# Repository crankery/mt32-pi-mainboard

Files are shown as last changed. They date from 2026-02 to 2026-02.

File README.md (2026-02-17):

# mt32-pi-mainboard

A host board for the [mt32-pi project](https://github.com/dwhinham/mt32-pi). I've tried to use nothing but cheap through-hole parts off Aliexpress for this to make it easy to build. I had one of the LCD2004 modules in a drawer which is why I used that huge thing. The board is 100x100mm which should be pretty cheap to get fabricated.

> [!NOTE]
> This is untested and probably doesn't work. If it ends up working, I'll make a 3D printable case for it.

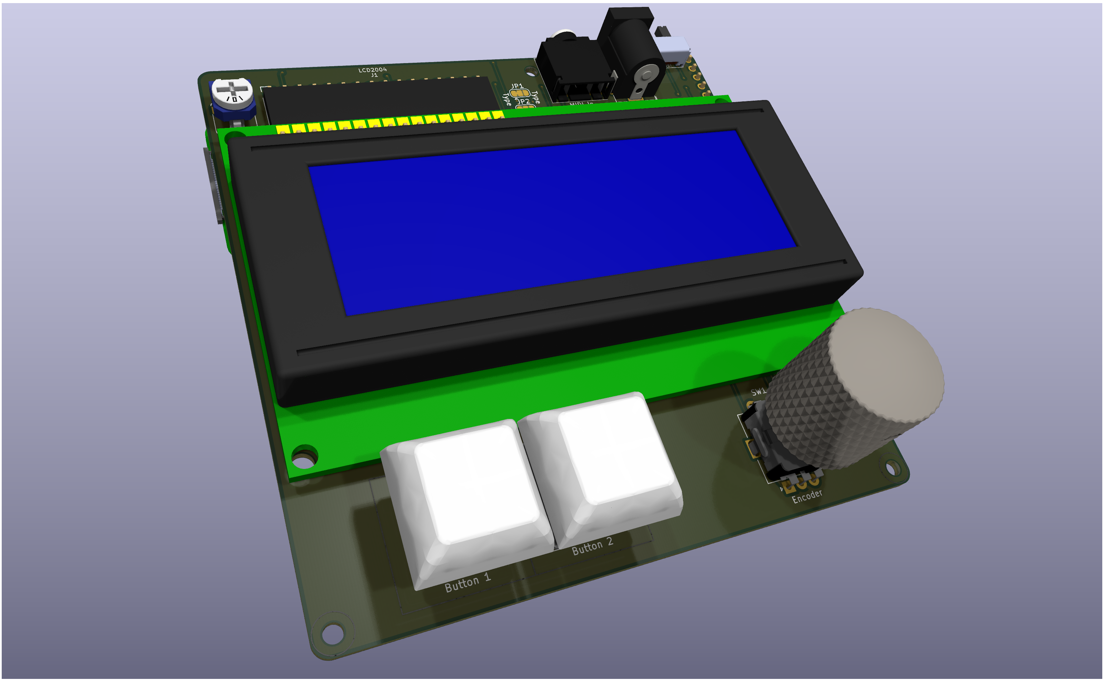
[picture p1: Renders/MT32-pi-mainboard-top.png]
Top


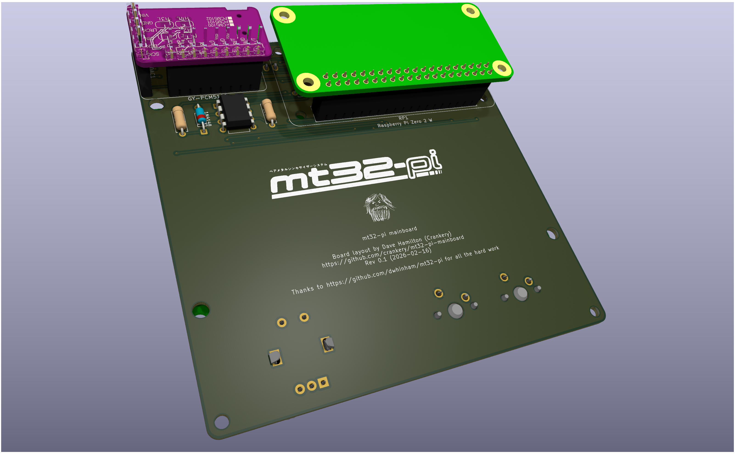
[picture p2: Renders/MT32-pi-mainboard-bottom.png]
Bottom


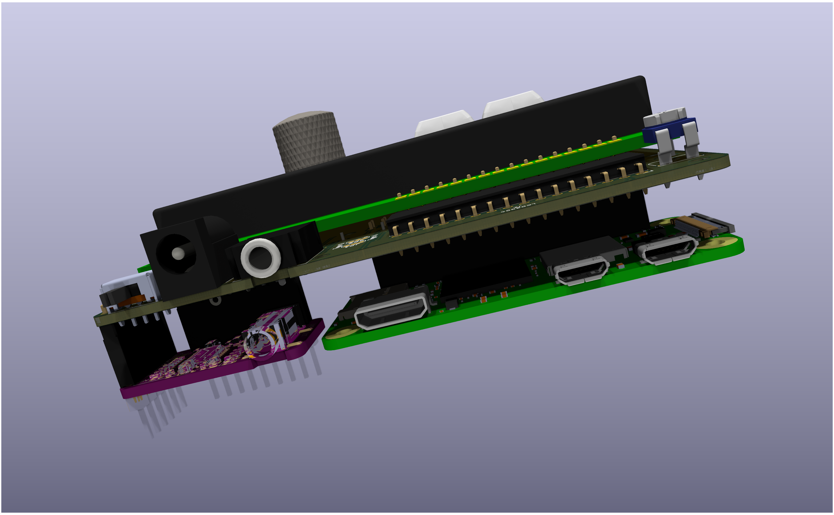
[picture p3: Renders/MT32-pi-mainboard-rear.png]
Rear


Yeah, the DAC module model I found has some weird transparancy issues in Kicad.

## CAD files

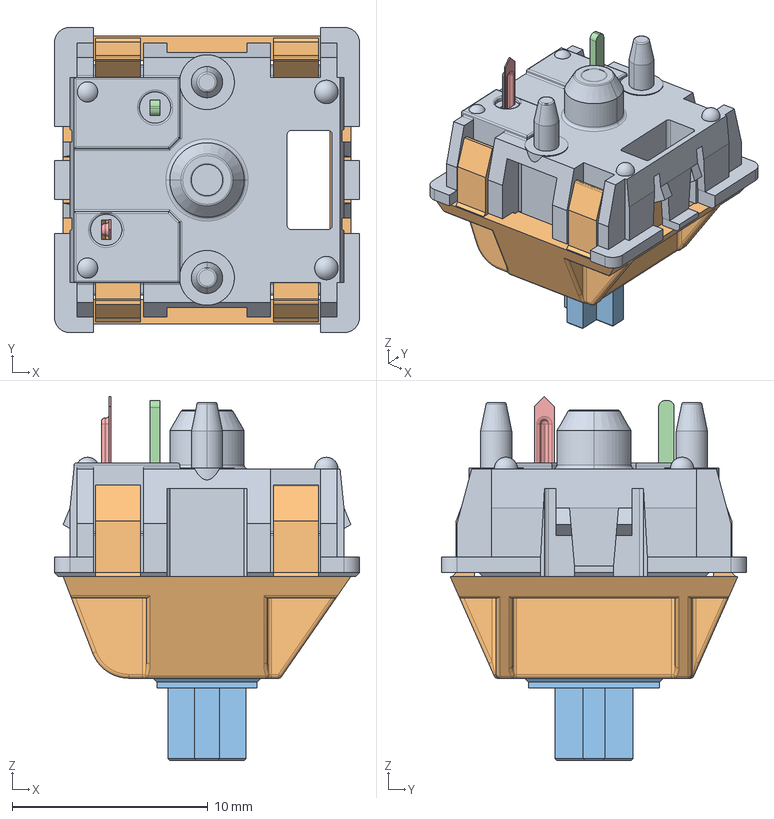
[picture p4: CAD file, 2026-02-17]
3D/asm_mx_asm_PCB.stp
15.6 x 15.6 x 18.6 mm
MX_DOWN
MX_UP
UP_MX
MX_PIN
MX_SPRING
MX_CLICK

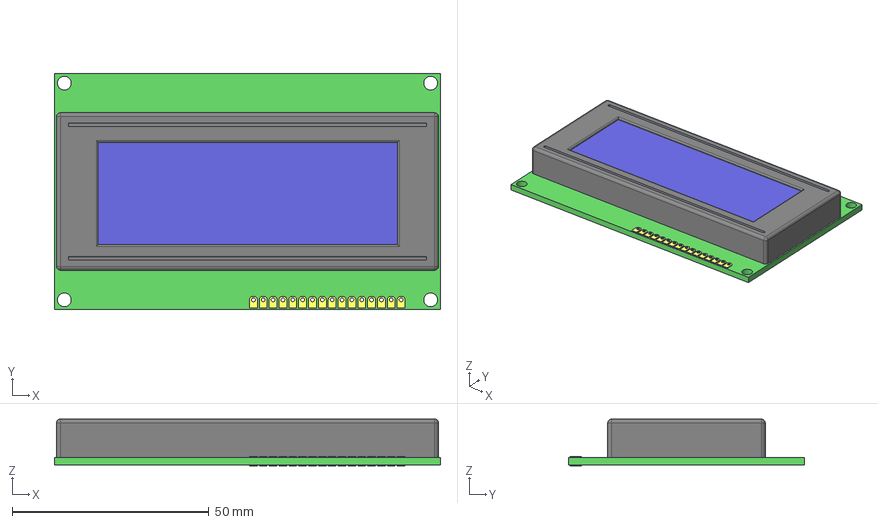
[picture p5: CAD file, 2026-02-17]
3D/LCD2004-simple.step
98.0 x 60.0 x 11.9 mm
LCD2007
PCB002
Islas001
Chasis002

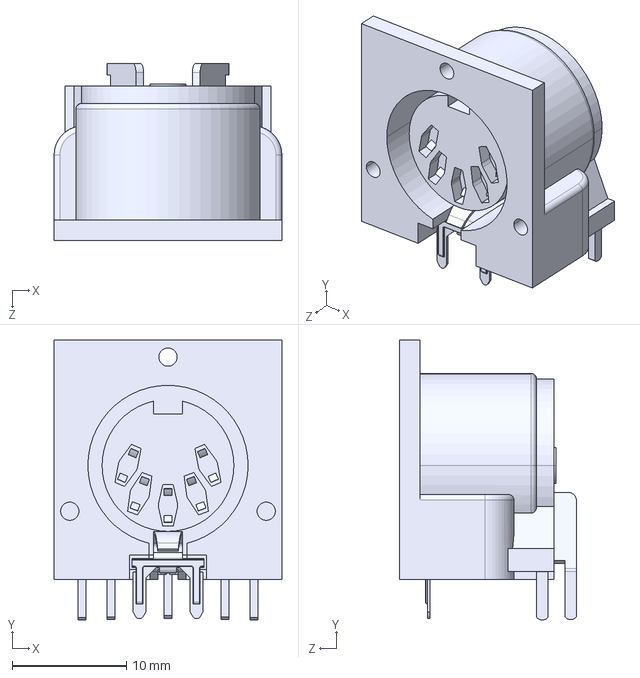
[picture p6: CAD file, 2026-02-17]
3D/57PC5F.step
20.0 x 24.5 x 15.5 mm

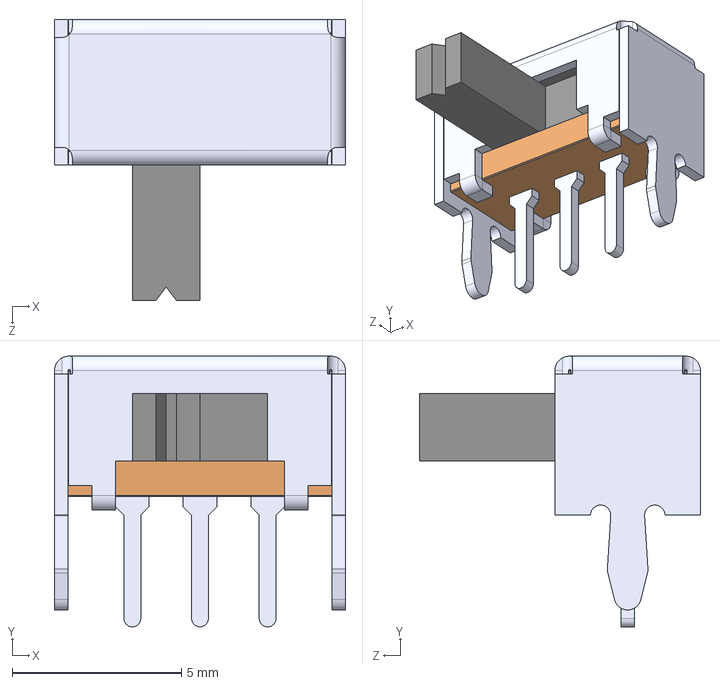
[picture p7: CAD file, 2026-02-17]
3D/SK12D07VG4.STEP
8.60 x 8.00 x 8.30 mm

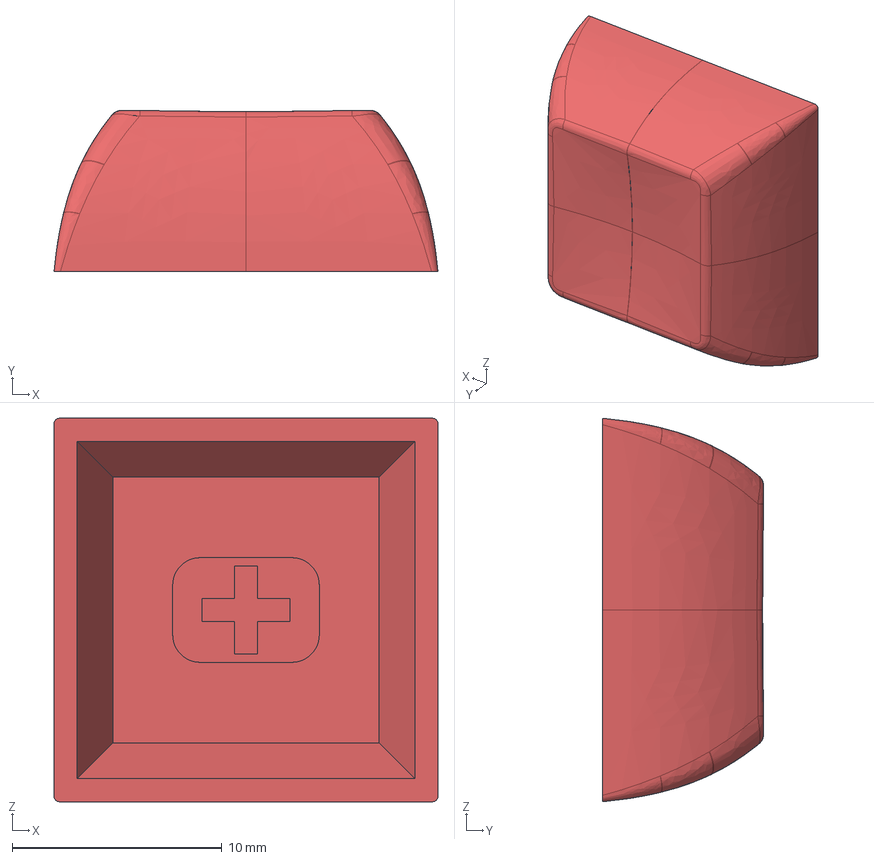
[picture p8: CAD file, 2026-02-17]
3D/DSA_Keycap_Red_CherryMX.step
18.3 x 7.69 x 18.3 mm

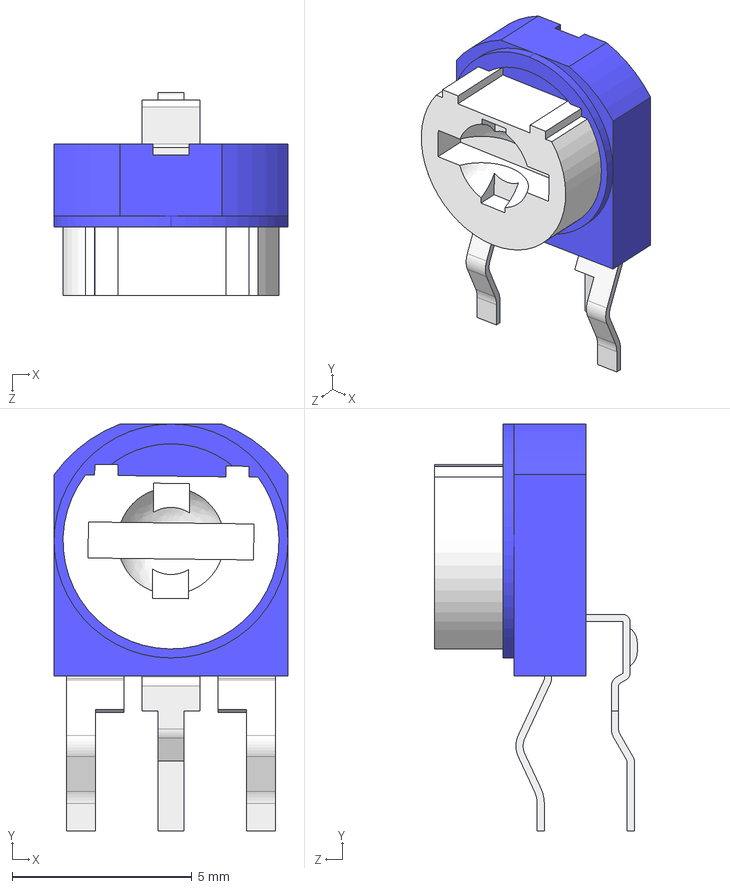
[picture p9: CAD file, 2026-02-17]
3D/RM-063.STEP
6.50 x 11.3 x 5.63 mm
User Library-RM-063_d1
User Library-RM-063_d2
User Library-RM-063_d3l
User Library-RM-063_d3r
User Library-RM-063_d3c

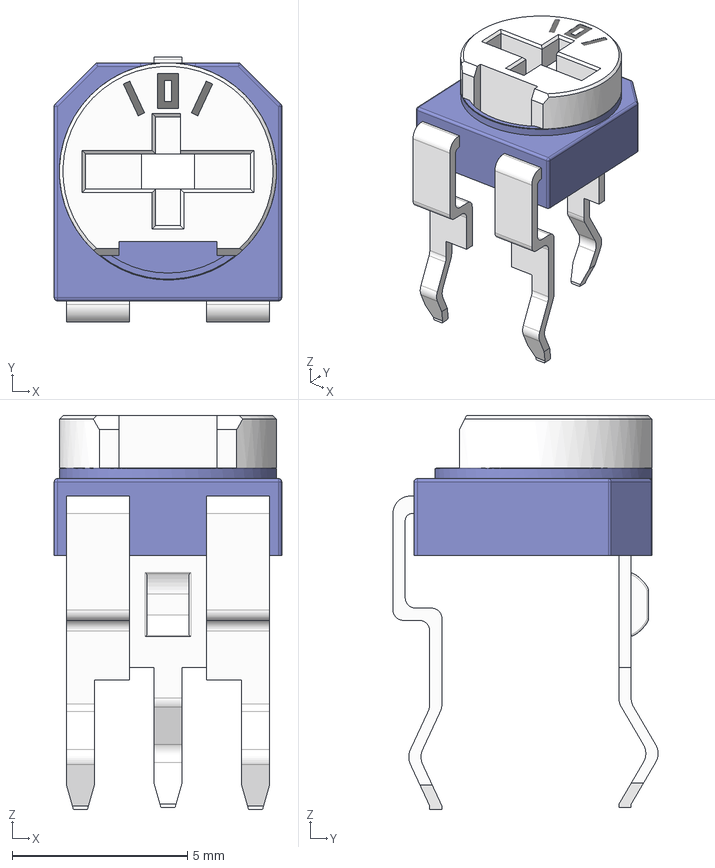
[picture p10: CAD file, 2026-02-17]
3D/RM-065.step
6.50 x 7.57 x 11.2 mm

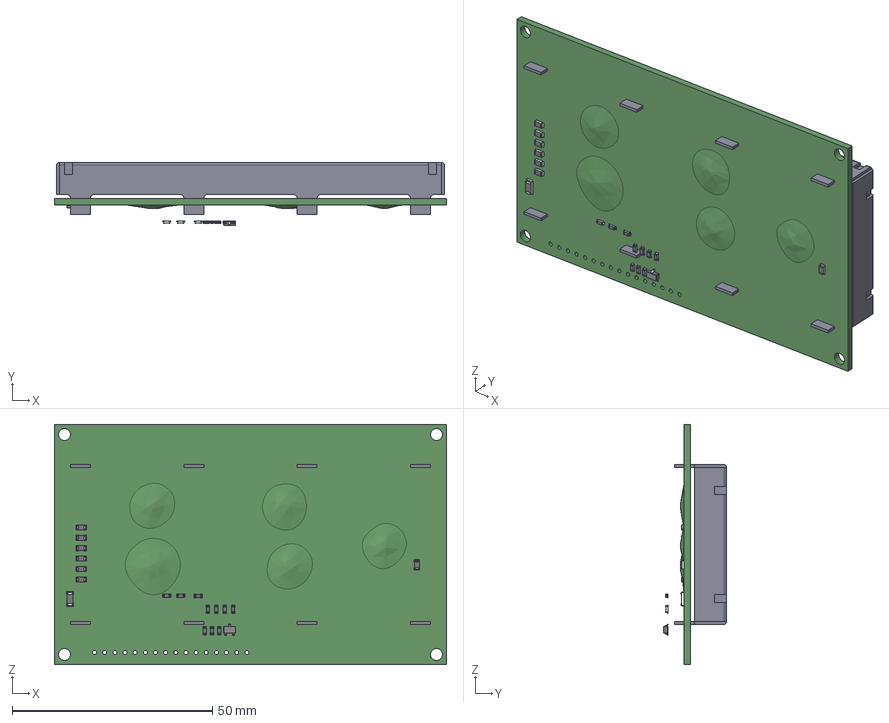
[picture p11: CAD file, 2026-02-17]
3D/lcd2004.step
98.0 x 15.8 x 60.0 mm
LCD2004 IIC_I2C, 20x4
LCD2004 IIC_I2C, 20x005
SMD rezistory_0603
SMD rezistory_0604
SMD rezistory_0605
SMD rezistory_0607
SMD rezistory_0608
SMD rezistory_0609
SMD rezistory_0611
SMD rezistory_0612
SMD rezistory_0613
SMD rezistory_0615
SMD rezistory_0616
SMD rezistory_0617
SMD rezistory_1206
SMD rezistory_1207
SMD rezistory_1208
SMD rezistory_0805
SMD rezistory_1210
SMD rezistory_1211
SMD rezistory_1213
SMD rezistory_1214
SMD rezistory_1215
SMD rezistory_1217
SMD rezistory_1218
SMD rezistory_1219
SMD rezistory_1221
SMD rezistory_1222
SMD rezistory_1223
SMD rezistory_1225
SMD rezistory_1226
SMD rezistory_1227
SMD rezistory_1229
SMD rezistory_1230
SMD rezistory_1231
SMD rezistory_1233
SMD rezistory_1234
SMD rezistory_1235
SMD rezistory_1237
SMD rezistory_1238
SMD rezistory_1239
SMD rezistory_1241
SMD rezistory_1242
SMD rezistory_1243
SMD rezistory_1245
SMD rezistory_1246
SMD rezistory_1247
SMD rezistory_1249
SMD rezistory_1250
SMD rezistory_1251
SMD rezistory_1253
SMD rezistory_1254
SMD rezistory_1255
SMD rezistory_1257
SMD rezistory_1258
SMD rezistory_1259
SOT23-3
SOT23-004
SOT23-005
SOT23-006

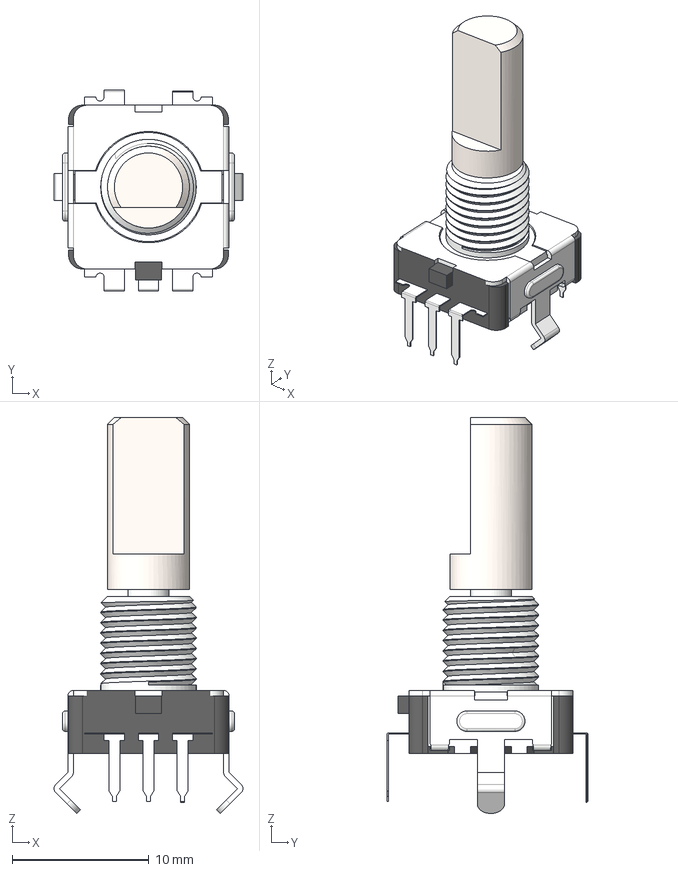
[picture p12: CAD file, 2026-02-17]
3D/SW-PEC11L-4220F-S0015.stp
13.8 x 14.7 x 29.0 mm

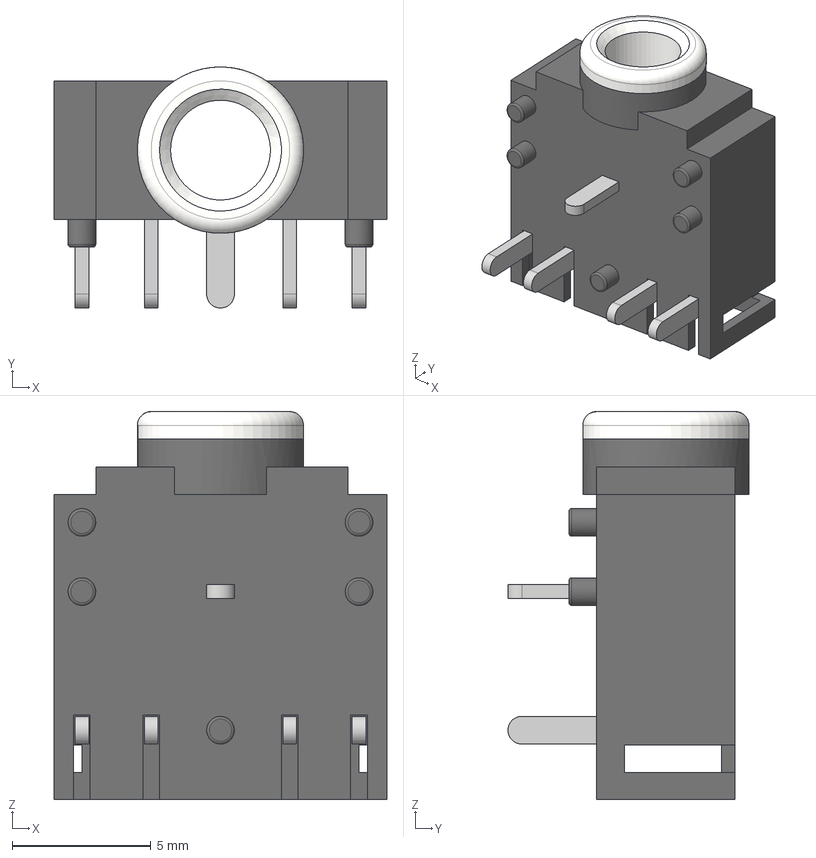
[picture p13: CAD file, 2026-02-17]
3D/pj-307.step
12.0 x 8.70 x 14.0 mm

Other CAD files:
3D/DSA_Keycap_White_CherryMX.step
3D/DSA_Keycap_Black_CherryMX.step

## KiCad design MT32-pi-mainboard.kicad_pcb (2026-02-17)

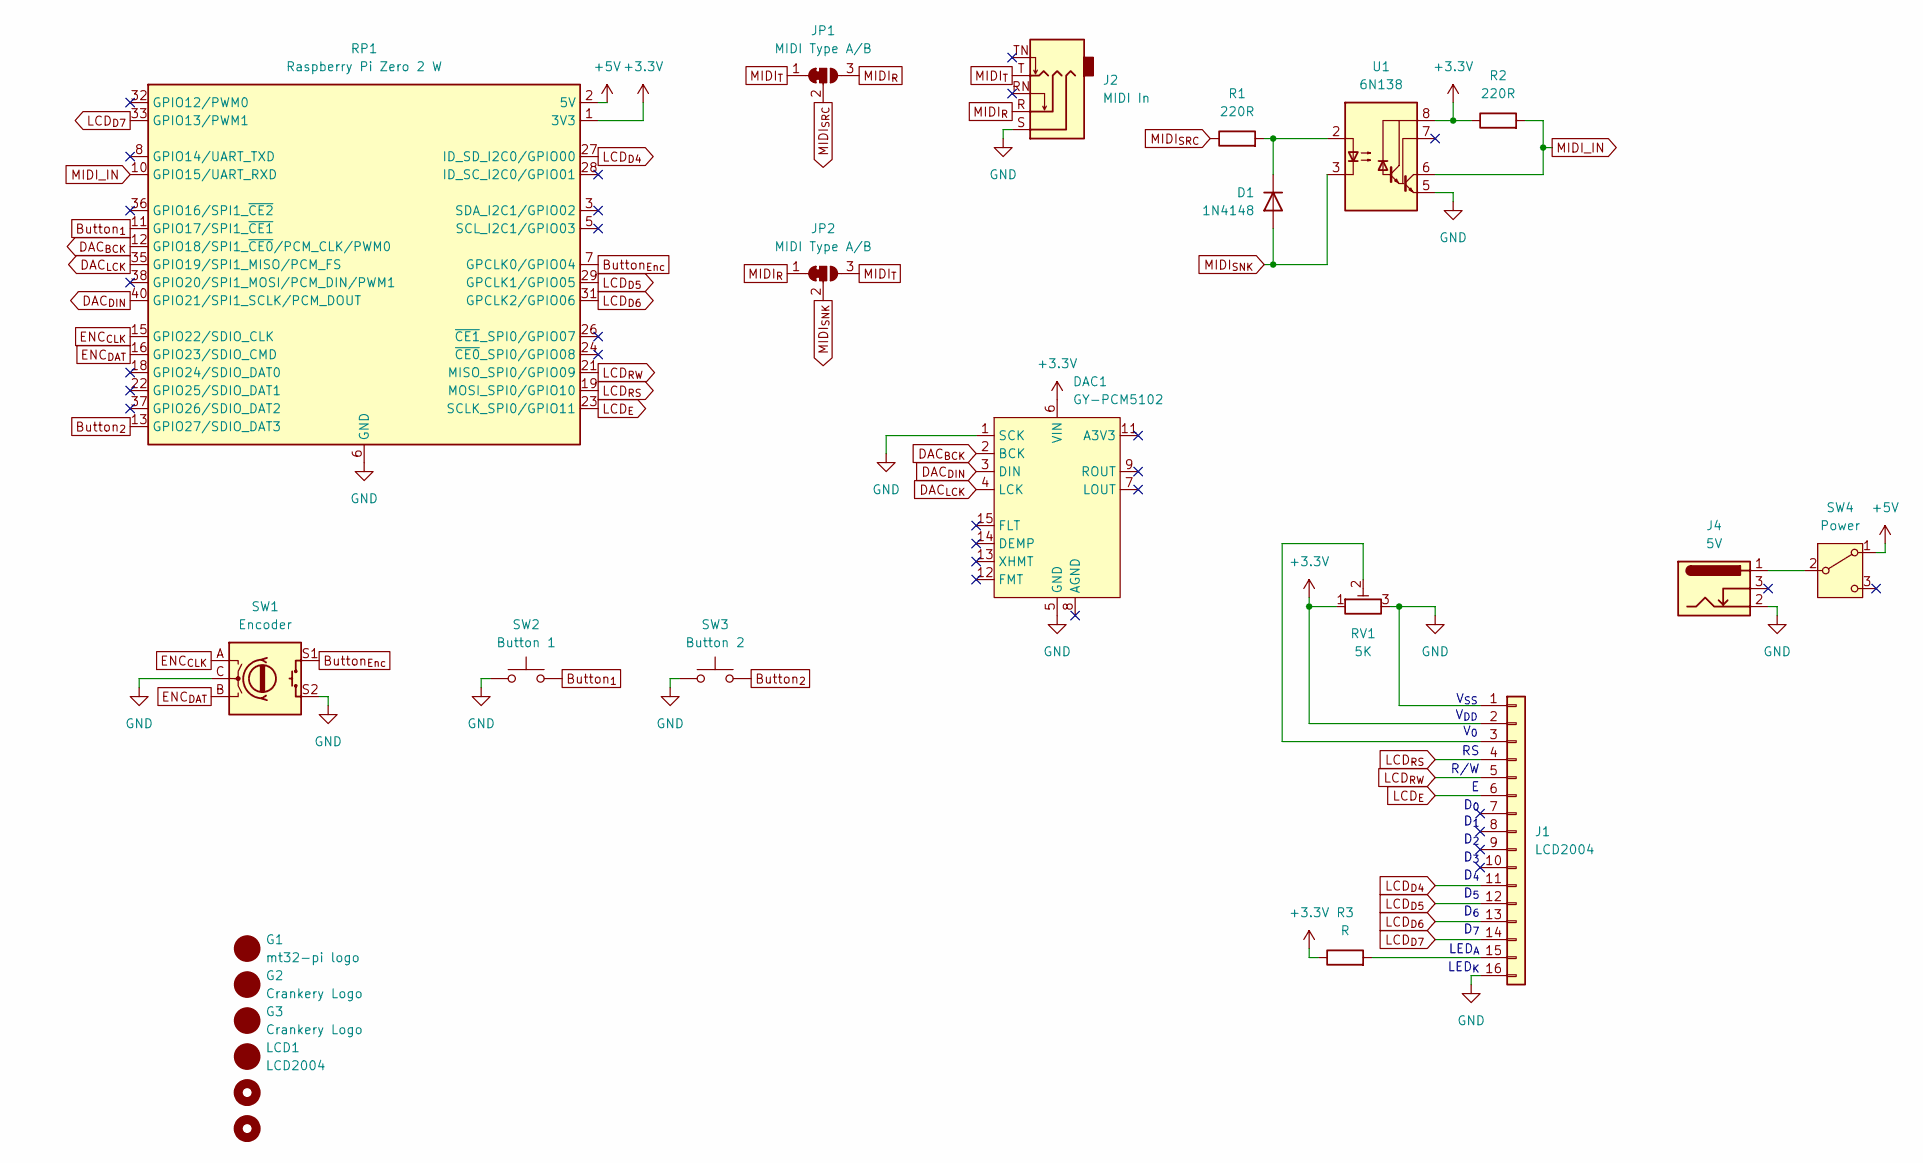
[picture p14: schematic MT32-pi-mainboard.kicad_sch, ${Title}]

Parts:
D1: 1N4148; D_DO-35_SOD27_P7.62mm_Horizontal
DAC1: GY-PCM5102
G1: mt32-pi logo; mt32-pi-logo
G2, G3: Crankery Logo; crankery_small
H2, H3: MountingHole; MountingHole_2.7mm_M2.5
J1: LCD2004; PinSocket_1x16_P2.54mm_Horizontal
J2: MIDI In; PJ-307
J4: 5V; BarrelJack_Horizontal
JP1, JP2: MIDI Type A/B; SolderJumper-3_P1.3mm_Bridged12_RoundedPad1.0x1.5mm
LCD1: LCD2004
R1, R2: 220R; R_Axial_DIN0207_L6.3mm_D2.5mm_P7.62mm_Horizontal
R3: R; R_Axial_DIN0207_L6.3mm_D2.5mm_P7.62mm_Horizontal
RP1: Raspberry Pi Zero 2 W; RP_Zero_2W
RV1: 5K; Potentiometer_Runtron_RM-065_Vertical
SW1: Encoder; RotaryEncoder_Alps_EC11E-Switch_Vertical_H20mm
SW2: Button 1; SW_Cherry_MX_1.00u_PCB
SW3: Button 2; SW_Cherry_MX_1.00u_PCB
SW4: Power; SK12D07VG4
U1: 6N138; DIP-8_W7.62mm

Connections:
+3.3V: DAC1.6 (VIN), J1.2, R2.1, R3.1, RP1.1 (3V3), RP1.17 (3V3), RV1.1, U1.8 (VCC)
+5V: RP1.2 (5V), RP1.4 (5V), SW4.1 (A)
Button_{1}: RP1.11 (GPIO17/SPI1_~CE1), SW2.2
Button_{2}: RP1.13 (GPIO27/SDIO_DAT3), SW3.2
Button_{Enc}: RP1.7 (GPCLK0/GPIO04), SW1.S1
DAC_{BCK}: DAC1.2 (BCK), RP1.12 (GPIO18/SPI1_~CE0/PCM_CLK/PWM0)
DAC_{DIN}: DAC1.3 (DIN), RP1.40 (GPIO21/SPI1_SCLK/PCM_DOUT)
DAC_{LCK}: DAC1.4 (LCK), RP1.35 (GPIO19/SPI1_MISO/PCM_FS)
ENC_{CLK}: RP1.15 (GPIO22/SDIO_CLK), SW1.A
ENC_{DAT}: RP1.16 (GPIO23/SDIO_CMD), SW1.B
GND: DAC1.1 (SCK), DAC1.5 (GND), J1.1, J1.16, J2.S, J4.2, RP1.6 (GND), RP1.9 (GND), RP1.14 (GND), RP1.20 (GND), RP1.25 (GND), RP1.30 (GND), RP1.34 (GND), RP1.39 (GND), RV1.3, SW1.C, SW1.S2, SW2.1, SW3.1, U1.5 (GND)
LCD_{D4}: J1.11, RP1.27 (ID_SD_I2C0/GPIO00)
LCD_{D5}: J1.12, RP1.29 (GPCLK1/GPIO05)
LCD_{D6}: J1.13, RP1.31 (GPCLK2/GPIO06)
LCD_{D7}: J1.14, RP1.33 (GPIO13/PWM1)
LCD_{E}: J1.6, RP1.23 (SCLK_SPI0/GPIO11)
LCD_{RS}: J1.4, RP1.19 (MOSI_SPI0/GPIO10)
LCD_{RW}: J1.5, RP1.21 (MISO_SPI0/GPIO09)
MIDI_IN: R2.2, RP1.10 (GPIO15/UART_RXD), U1.6 (VO2)
MIDI_{R}: J2.R, JP1.3 (B), JP2.1 (A)
MIDI_{SNK}: D1.2 (A), JP2.2 (C), U1.3 (C2)
MIDI_{SRC}: JP1.2 (C), R1.1
MIDI_{T}: J2.T, JP1.1 (A), JP2.3 (B)
unnamed: D1.1 (K), R1.2, U1.2 (C1)
unnamed: J1.3, RV1.2
unnamed: J1.15, R3.2
unnamed: J4.1, SW4.2 (B)

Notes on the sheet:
D_{7}
LED_{A}
D_{6}
D_{1}
R/W
LED_{K}
V_{SS}
V_{0}
D_{3}
D_{2}
D_{4}
D_{5}
D_{0}
V_{DD}

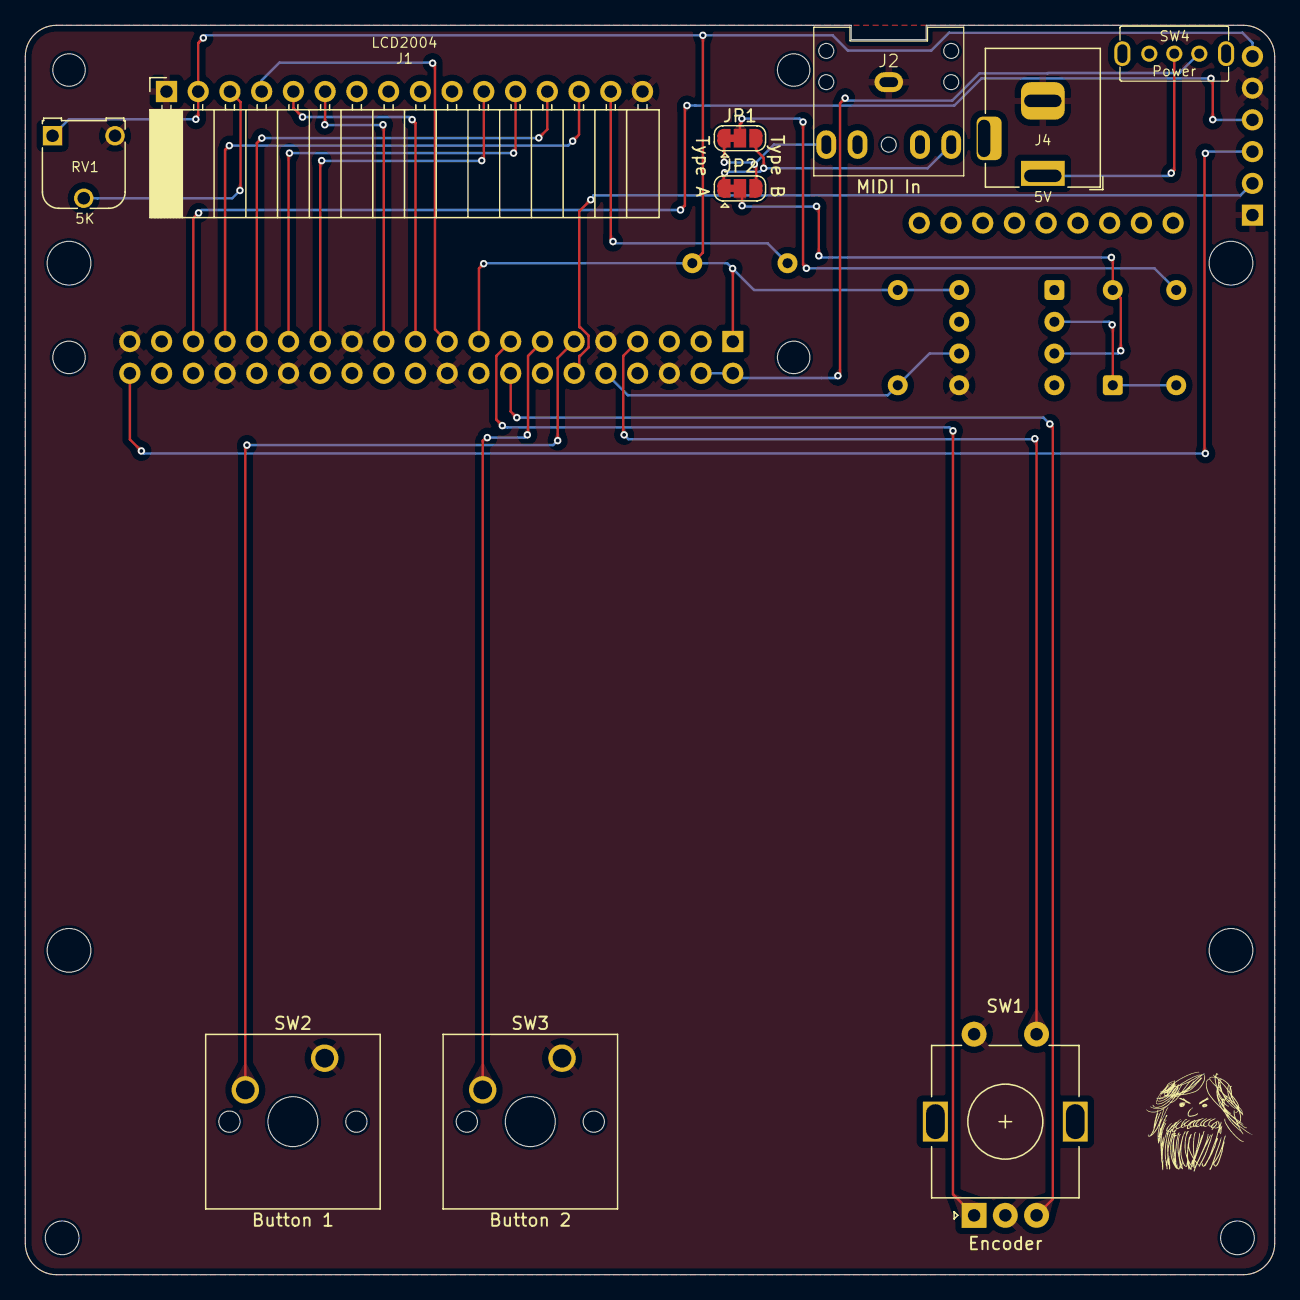
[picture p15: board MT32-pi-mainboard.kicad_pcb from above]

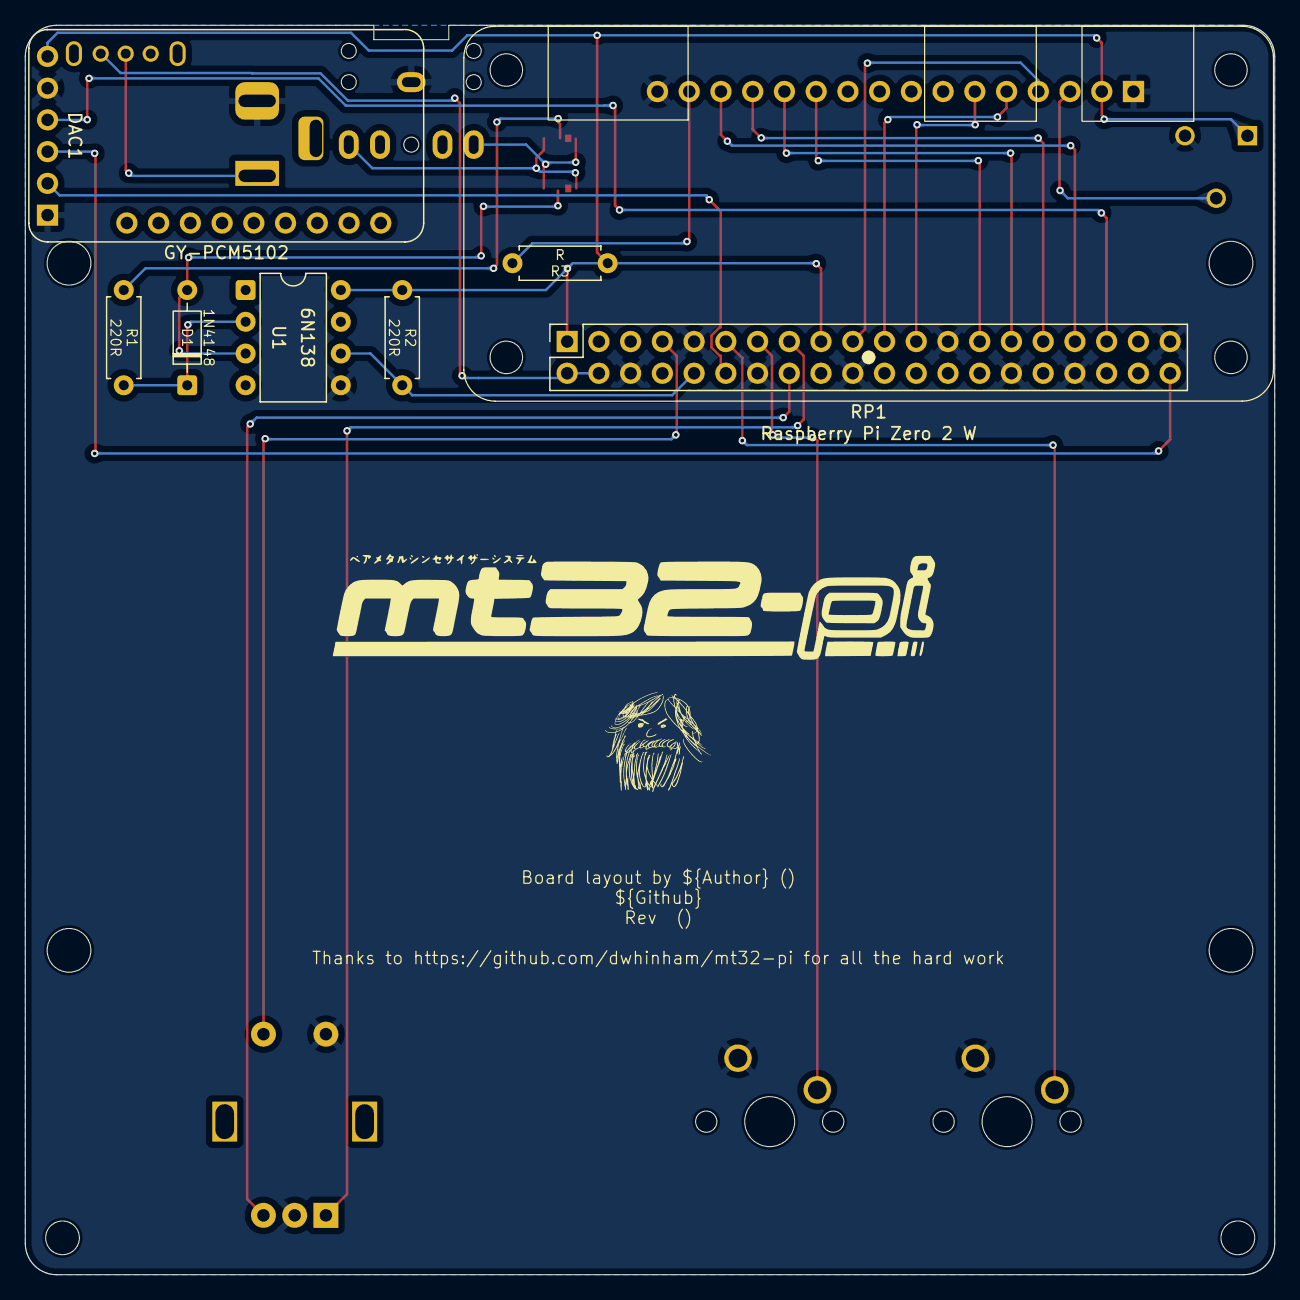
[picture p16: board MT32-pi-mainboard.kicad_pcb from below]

Board: 2 copper layers, 100.0 x 100.0 mm, 23 parts (7 on the bottom side), 27 nets.

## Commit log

2026-02-17 Update README with project details and notes
    Expanded description of the mt32-pi project and added note about potential 3D printable case.
2026-02-17 add symbols for virtual models and graphics
    [MT32-pi-mainboard.kicad_pcb, MT32-pi-mainboard.kicad_sch]
2026-02-17 cleanup, add gerbers
    [MT32-pi-mainboard-B_Cu.gbr, MT32-pi-mainboard-B_Mask.gbr, MT32-pi-mainboard-B_Paste.gbr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]
2026-02-17 clean up silks, use project properties for text
    [MT32-pi-mainboard.kicad_pcb, MT32-pi-mainboard.kicad_sch]
2026-02-17 regenerate gerbers
    [MT32-pi-mainboard-B_Cu.gbr, MT32-pi-mainboard-B_Mask.gbr, MT32-pi-mainboard-B_Paste.gbr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]
2026-02-17 add some renders and the zipped gerbers
